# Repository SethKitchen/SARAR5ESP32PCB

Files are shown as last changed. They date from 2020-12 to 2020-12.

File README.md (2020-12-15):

# SARAR5ESP32PCB
An IoT PCB integrating the ESP32 and ublox SARA-R5 . Allows for 5G Cellular, Wi-Fi, and Bluetooth in the same device with low form-factor.

This was an open source contibution sponsored by @hiperionio . Thanks so much! If you like what I'm doing please consider sponsoring as well!

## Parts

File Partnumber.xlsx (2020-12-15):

 |  | Manufacturer | MPN | Comments
10uF | C0402 | Samsung Electro-Mechanics | CL05A106MP8NUB8
1uF | C0402 | Murata Electronics | GRM155R61E105KA12D
100nF | C0402 | AVX Corporation | FS055C104K4Z2A
10nF | C0402 | Murata Electronics | GRM155R71E103KA01D
68pF | C0402 | Yageo | CC0402JRNPO9BN680
15pF | C0402 | KEMET | C0402C150K5GACTU
27pf GRM1555C1... | C0402 | Murata Electronics | GRM1555C1H270JA01J
33pf GRM1555C1... | C0402 | Murata Electronics | GRM1555C1H330JA01D
PESD0402-140 | DIONC1005X43N | Littelfuse Inc. | PESD0402-140
RED | LED-0603 | Broadcom Limited | HSMC-C190
BLUE | LED-0603 | Lite-On Inc. | LTST-C194TBKT
BLUE | LED-0603 | Lite-On Inc. | LTST-C194TBKT
BAT20J | SOD-323 | STMicroelectronics | BAT20JFILM
ANTENNA | TRACE_ANTENNA |  |  | On board PCB antenna
500mA | PTC-1206 | Littelfuse Inc. | 1206L025YR
M20 | 1x20_NOSILK | Amphenol ICC (FCI) | 68000-220HLF
MICROB-PLUG | USB-B-MICRO-SM... | SparkFun | PRT-08533
39nH | L0402 | Murata Electronics | LQG15HN39NJ02D
LQG15HS68NJ02B | LQG15WH0N7B02D | Murata Electronics | LQG15HS68NJ02D
2.7nH | 603 | TDK Electronics Inc. | B82496C3279A000
MBT3904DW1T1 | SC70-6 | ON Semiconductor | MBT3904DW1T3G
RESET | TACTILE_SWITCH | C&K | KMR232GULCLFS
BTN-0 | TACTILE_SWITCH | C&K | KMR232GULCLFS
PAD-JUMPER-3-2O | PAD-JUMPER-3-2O... |  |  | Will not place
JUMPER-PAD-2-N | PAD-JUMPER-2-N... | Yageo | RC0402JR-070RL | Will not place
BC847 | SOT23 | Nexperia | BC847,215
GRM1555C1E680J | INDC1005X45 | Yageo | CC0402JRNPO9BN680
MAX-8 | MAX-8 | U-Blox | MAX-8Q-0-10
AP2112K-3.3V | SOT23-5 | Diodes Incorporated | AP2112K-3.3TRG1
ESP3212 | QFN48-0.4MM | Espressif Systems | ESP32-D0WD
SN74AVC4T774 | TSSOP16 | Texas Instruments | SN74AVC4T774PW
SARA-R5 | Sara-R5 | U-Blox | SARA-R511M
W25Q32FVSS | SOIC-8 | Winbond | W25Q32JVSSIQS
F231XS | SSOP20_L | FTDI, Future Technology Devices International Ltd | FT231XS-R
LTI-SASF54GT | LTI-SASF54GT | Würth Elektronik | 60312002114503
CCM03-3013LFT_... | C&K_CCM03-3013... | C&K | CCM03-3013LFT R102
26MHz | CRYSTAL_SMD-3.2… | ABRACON | ABM3BAIG-26.000MHZ-1Z-T
32.768kHz | CRYSTAL_SMD-3.2... | ABRACON | ABS07W-32.768kHz-K-2-T

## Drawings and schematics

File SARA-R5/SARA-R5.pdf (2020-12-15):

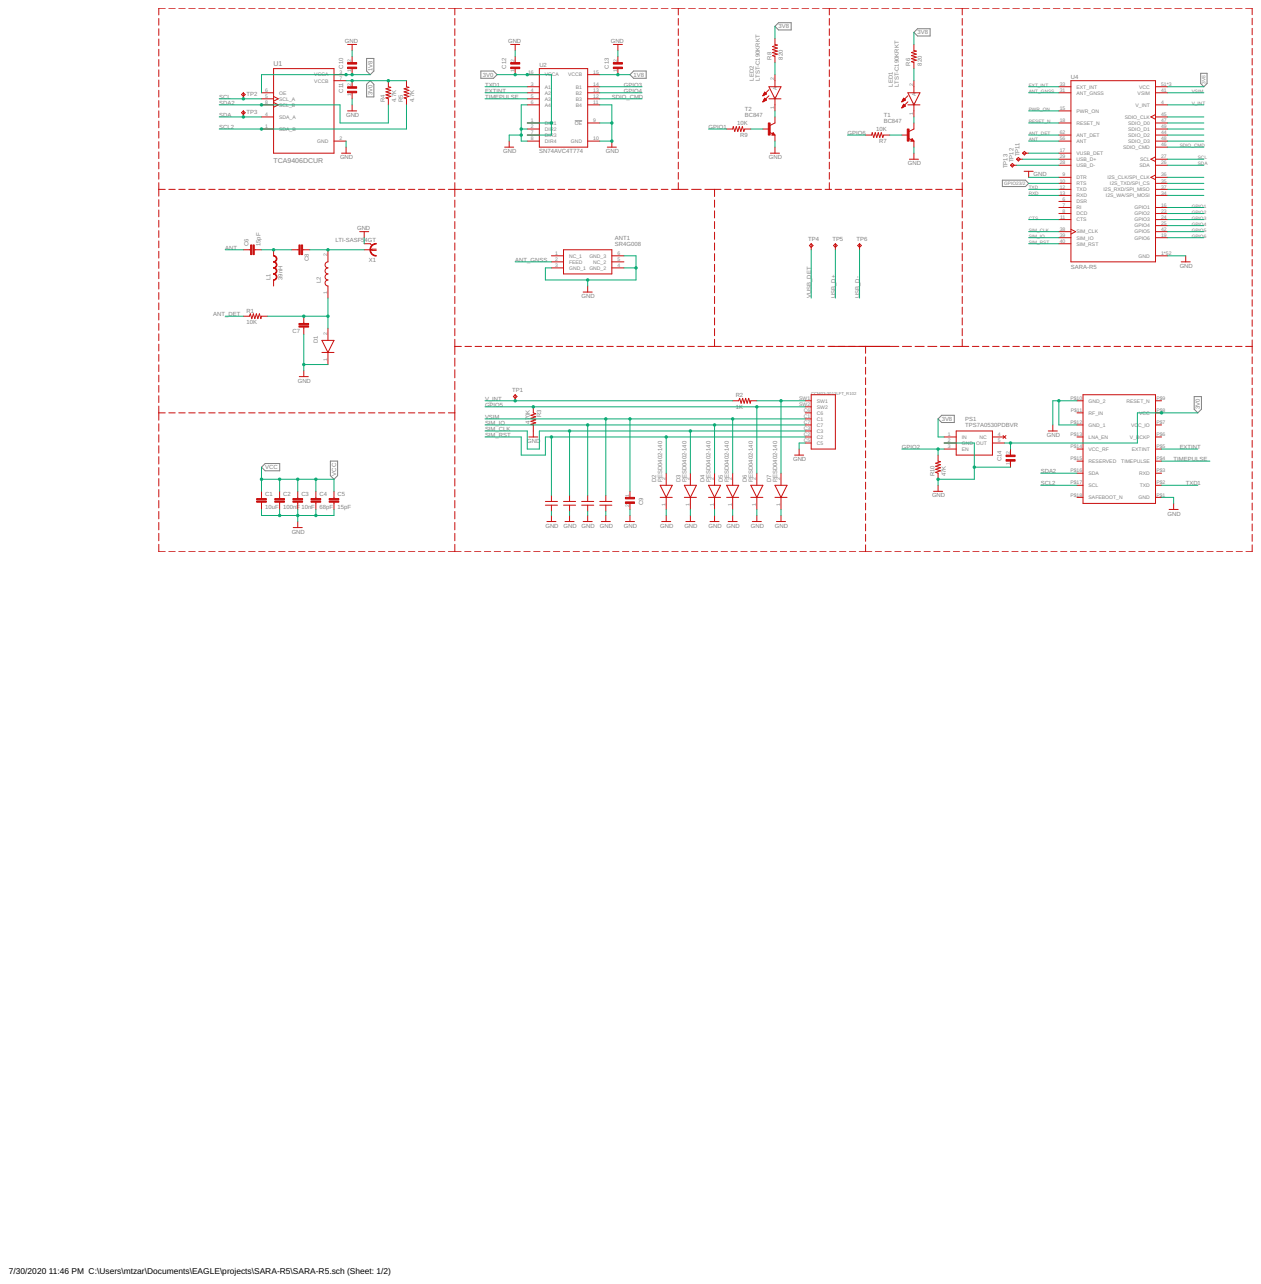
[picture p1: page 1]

7/30/2020 11:46 PM C:\Users\mtzar\Documents\EAGLE\projects\SARA-R5\SARA-R5.sch (Sheet: 1/2)

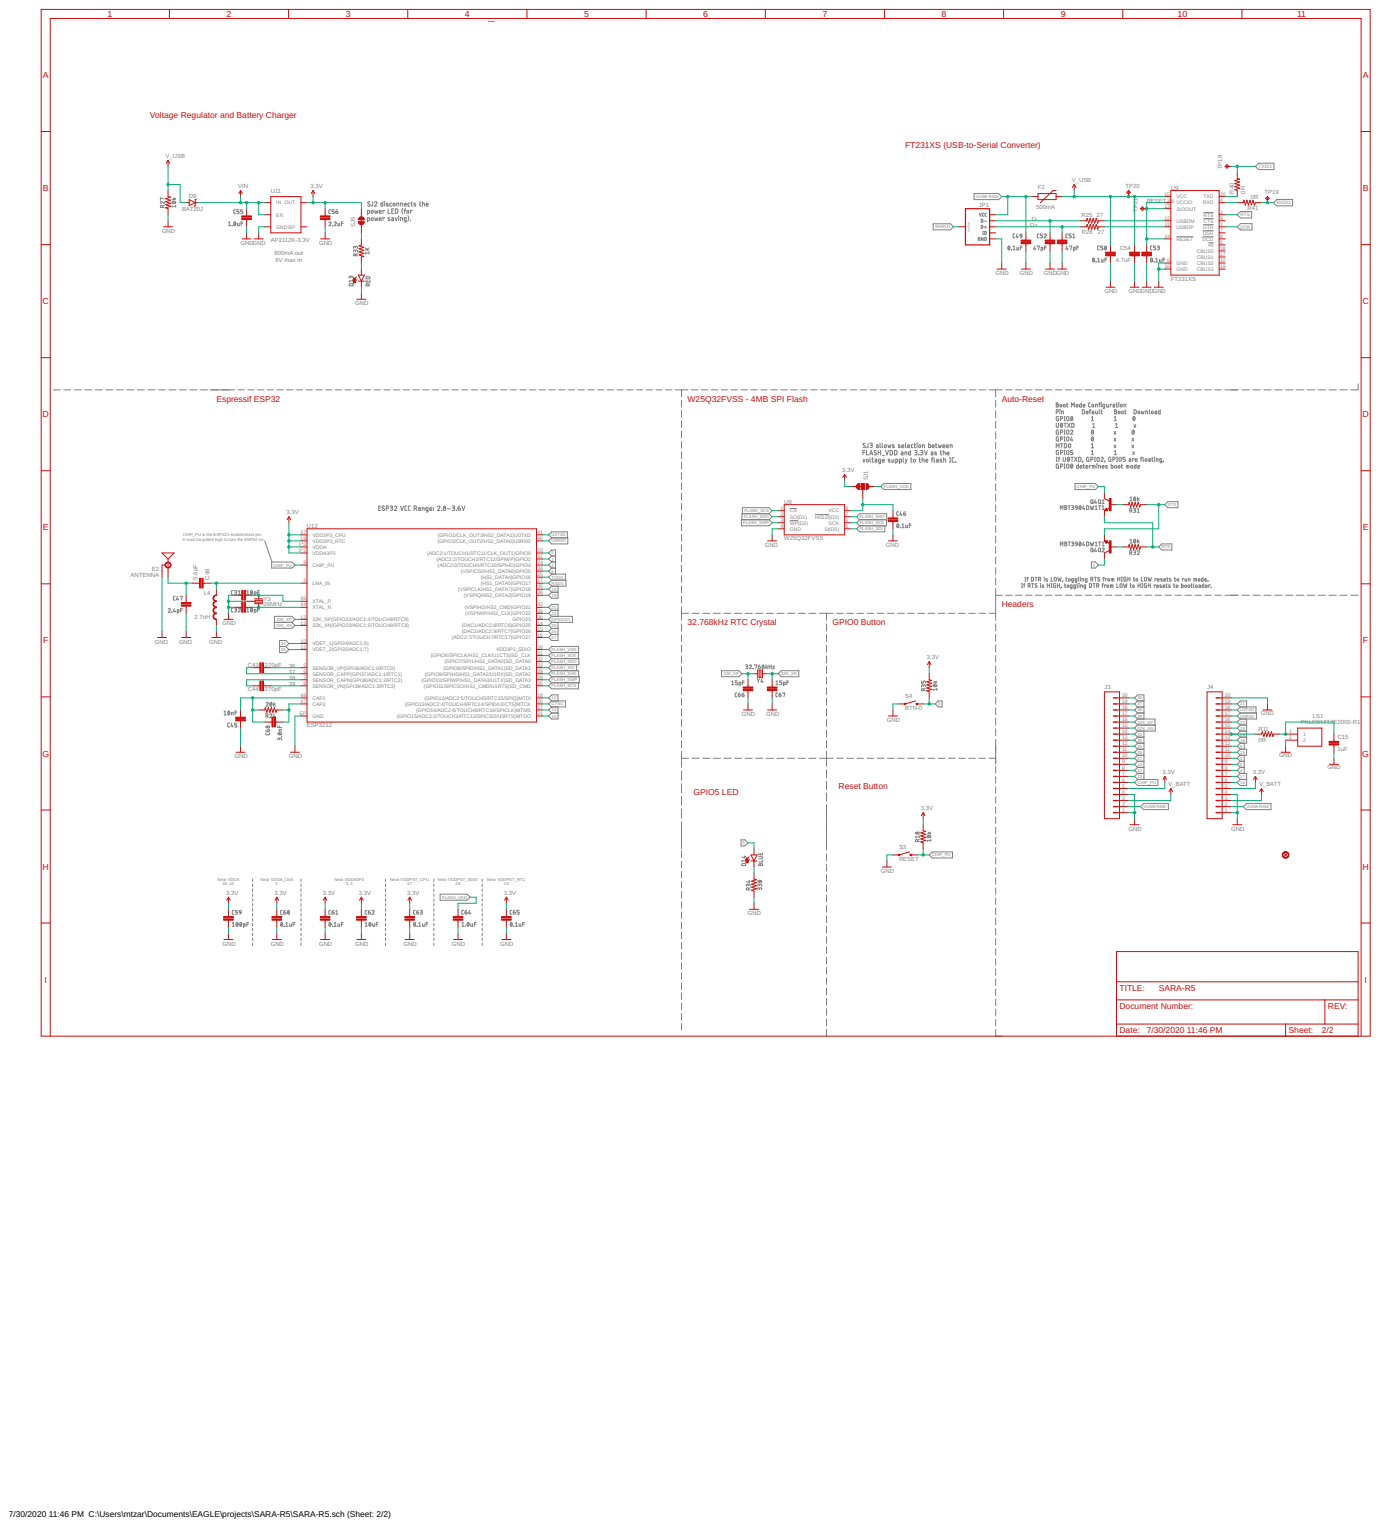
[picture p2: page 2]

Voltage Regulator and Battery Charger

FT231XS (USB-to-Serial Converter)

FLASH_SDO | FLASH_SHD
FLASH_SWP | FLASH_SCK

CHIP_PU is the ESP32's enable/reset pin.

Document Number: | REV:

Date: 7/30/2020 11:46 PM | Sheet: 2/2

7/30/2020 11:46 PM C:\Users\mtzar\Documents\EAGLE\projects\SARA-R5\SARA-R5.sch (Sheet: 2/2)

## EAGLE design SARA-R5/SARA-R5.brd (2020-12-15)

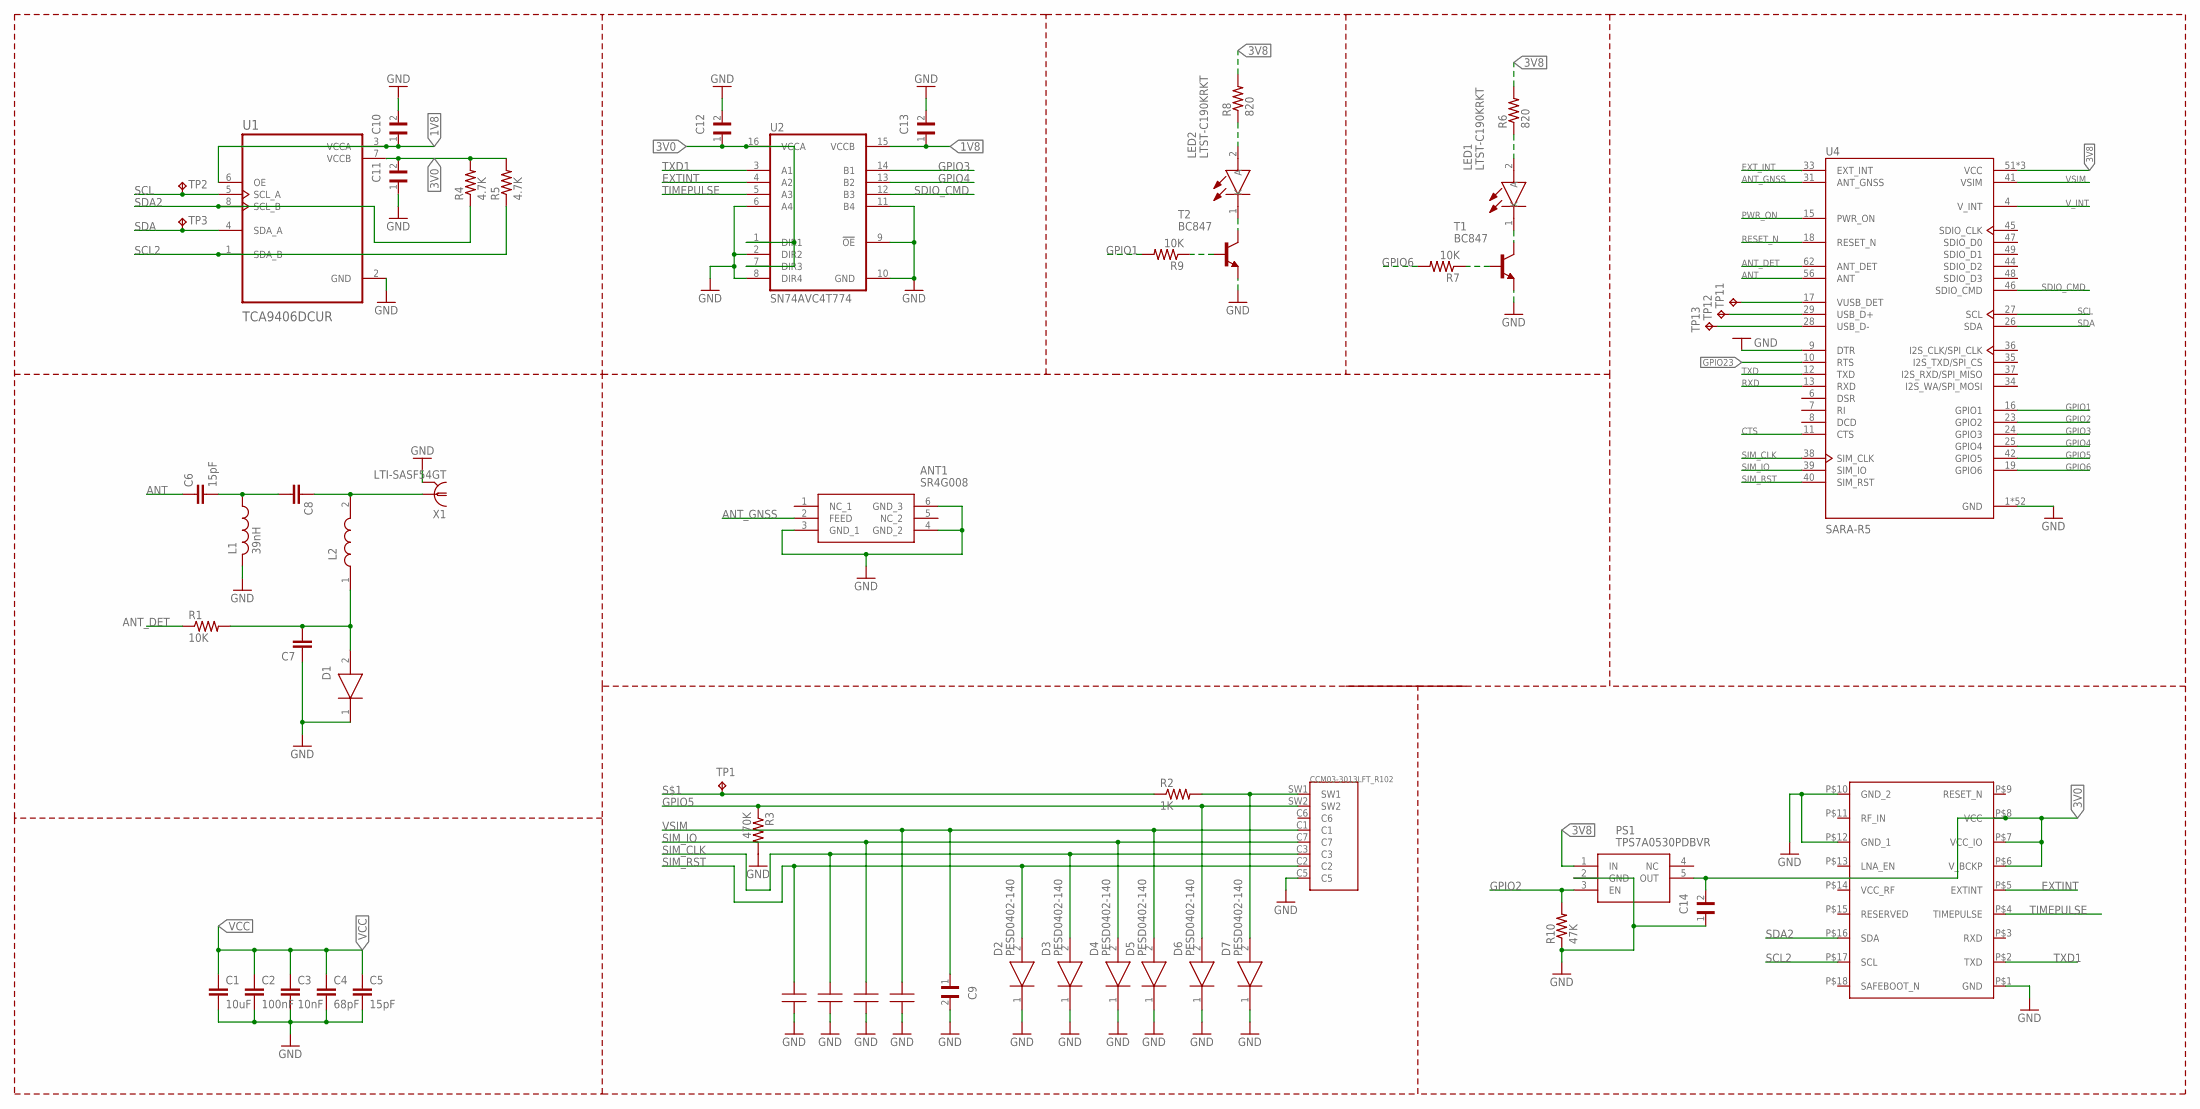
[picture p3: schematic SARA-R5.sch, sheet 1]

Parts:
ANT1: SR4G008
C1: 10uF; C0402
C2: 100nF; C0402
C3: 10nF; C0402
C4: 68pF; C0402
C5, C6: 15pF; C0402
C7: 27pF GRM1555C1H270JA16; C0402
C8: 33pF GRM1555C1H330JA16; C0402
C9, C10, C11, C12, C13, C14: GCM155R71C104KA55J; CAPC1005X55N
D1, D2, D3, D4, D5, D6, D7: PESD0402-140; DIONC1005X43N
L1: 39nH; L0402
L2: LQG15HS68NJ02B; LQG15WH0N7B02D
LED1, LED2: LTST-C190KRKT; LEDC1608X80N
PS1: TPS7A0530PDBVR; SOT95P280X145-5N
R1, R7, R9: 10K; R0402
R2: 1K; R0402
R3: 470K; R0402
R4, R5: 4.7K; R0402
R6, R8: 820; R0402
R10: 47K; R0402
T1, T2: BC847; SOT23
TP1: TPB2,54; B2,54
TP2, TP3, TP11, TP12, TP13: TPB1,27; B1,27
U1: TCA9406DCUR; SOP50P310X90-8N
U2: SN74AVC4T774; TSSOP16
U4: SARA-R5
U$1, U$2, U$3, U$4: GRM1555C1E680JA01; INDC1005X45
U$5: MAX-8
X1: LTI-SASF54GT
X2: CCM03-3013LFT_R102; C&K_CCM03-3013LFTR102

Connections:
1V8: C10.1, C13.1, U1.3 (VCCA), U1.6 (OE), U2.15 (VCCB)
3V0: C11.2, C12.1, C14.2, PS1.5 (OUT), R4.2, R5.2, U1.7 (VCCB), U2.1 (DIR1), U2.7 (DIR3), U2.16 (VCCA), U$5.P$6 (V_BCKP), U$5.P$7 (VCC_IO), U$5.P$8 (VCC)
3V8: PS1.1 (IN), R6.2, R8.2, U4.51 (VCC), U4.52 (VCC), U4.53 (VCC)
ANT: C6.1, U4.56 (ANT)
ANT_DET: R1.1, U4.62 (ANT_DET)
ANT_GNSS: ANT1.2 (FEED), U4.31 (ANT_GNSS)
CTS: U4.11 (CTS); also elsewhere on the board
EXTINT: U2.4 (A2), U$5.P$5 (EXTINT)
EXT_INT: U4.33 (EXT_INT)
GND: ANT1.3 (GND_1), ANT1.4 (GND_2), ANT1.6 (GND_3), C1.2, C2.2, C3.2, C4.2, C5.2, C7.1, C9.2, C10.2, C11.1, C12.2, C13.2, C14.1, D1.1 (K), D2.1 (K), D3.1 (K), D4.1 (K), D5.1 (K), D6.1 (K), D7.1 (K), L1.2, PS1.2 (GND), R3.2, R10.1, T1.2 (E), T2.2 (E), U1.2 (GND), U2.2 (DIR2), U2.6 (A4), U2.8 (DIR4), U2.9 (!OE!), U2.10 (GND), U2.11 (B4), U4.1 (GND), U4.3 (GND), U4.5 (GND), U4.9 (DTR), U4.14 (GND), U4.20 (GND), U4.21 (GND), U4.22 (GND), U4.30 (GND), U4.32 (GND), U4.43 (GND), U4.50 (GND), U4.54 (GND), U4.55 (GND), U4.57 (GND), U4.58 (GND), U4.59 (GND), U4.60 (GND), U4.61 (GND), U4.63 (GND), U4.64 (GND), U4.65 (GND), U4.66 (GND), U4.67 (GND), U4.68 (GND), U4.69 (GND), U4.70 (GND), U4.71 (GND), U4.72 (GND), U4.73 (GND), U4.74 (GND), U4.75 (GND), U4.76 (GND), U4.77 (GND), U4.78 (GND), U4.79 (GND), U4.80 (GND), U4.81 (GND), U4.82 (GND), U4.83 (GND), U4.84 (GND), U4.85 (GND), U4.86 (GND), U4.87 (GND), U4.88 (GND), U4.89 (GND), U4.90 (GND), U4.91 (GND), U4.92 (GND), U4.93 (GND), U4.94 (GND), U4.95 (GND), U4.96 (GND), U$1.2, U$2.2, U$3.2, U$4.2, U$5.P$1 (GND), U$5.P$10 (GND_2), U$5.P$12 (GND_1), X1.2, X1.3 (2), X1.4 (2), X1.5 (2), X2.C5; also elsewhere on the board
GPIO1: R9.2, U4.16 (GPIO1)
GPIO2: PS1.3 (EN), R10.2, U4.23 (GPIO2)
GPIO3: U2.14 (B1), U4.24 (GPIO3)
GPIO4: U2.13 (B2), U4.25 (GPIO4)
GPIO5: D6.2 (A), R3.1, U4.42 (GPIO5), X2.SW2
GPIO6: R7.2, U4.19 (GPIO6)
GPIO23: U4.10 (RTS); also elsewhere on the board
unnamed: C7.2, D1.2 (A), L2.1, R1.2
unnamed: C6.2, C8.2, L1.1
unnamed: D7.2 (A), R2.2, X2.SW1
unnamed: LED1.2 (A), R6.1
unnamed: C8.1, L2.2, X1.1
unnamed: LED1.1 (K), T1.3 (C)
unnamed: R7.1, T1.1 (B)
unnamed: LED2.2 (A), R8.1
unnamed: LED2.1 (K), T2.3 (C)
unnamed: R9.1, T2.1 (B)
unnamed: TP11.TP, U4.17 (VUSB_DET)
unnamed: TP12.TP, U4.29 (USB_D+)
unnamed: TP13.TP, U4.28 (USB_D-)
PWR_ON: U4.15 (PWR_ON); also elsewhere on the board
RESET_N: U4.18 (RESET_N); also elsewhere on the board
RXD: U4.13 (RXD); also elsewhere on the board
S$1: R2.1, TP1.TP
SCL: TP2.TP, U1.5 (SCL_A), U4.27 (SCL)
SCL2: R5.1, U1.1 (SDA_B), U$5.P$17 (SCL)
SDA: TP3.TP, U1.4 (SDA_A), U4.26 (SDA)
SDA2: R4.1, U1.8 (SCL_B), U$5.P$16 (SDA)
SDIO_CMD: U2.12 (B3), U4.46 (SDIO_CMD)
SIM_CLK: D3.2 (A), U4.38 (SIM_CLK), U$2.1, X2.C3
SIM_IO: D4.2 (A), U4.39 (SIM_IO), U$3.1, X2.C7
SIM_RST: D2.2 (A), U4.40 (SIM_RST), U$1.1, X2.C2
TIMEPULSE: U2.5 (A3), U$5.P$4 (TIMEPULSE)
TXD: U4.12 (TXD); also elsewhere on the board
TXD1: U2.3 (A1), U$5.P$2 (TXD)
VCC: C1.1, C2.1, C3.1, C4.1, C5.1
VSIM: C9.1, D5.2 (A), U4.41 (VSIM), U$4.1, X2.C1
V_INT: U4.4 (V_INT)

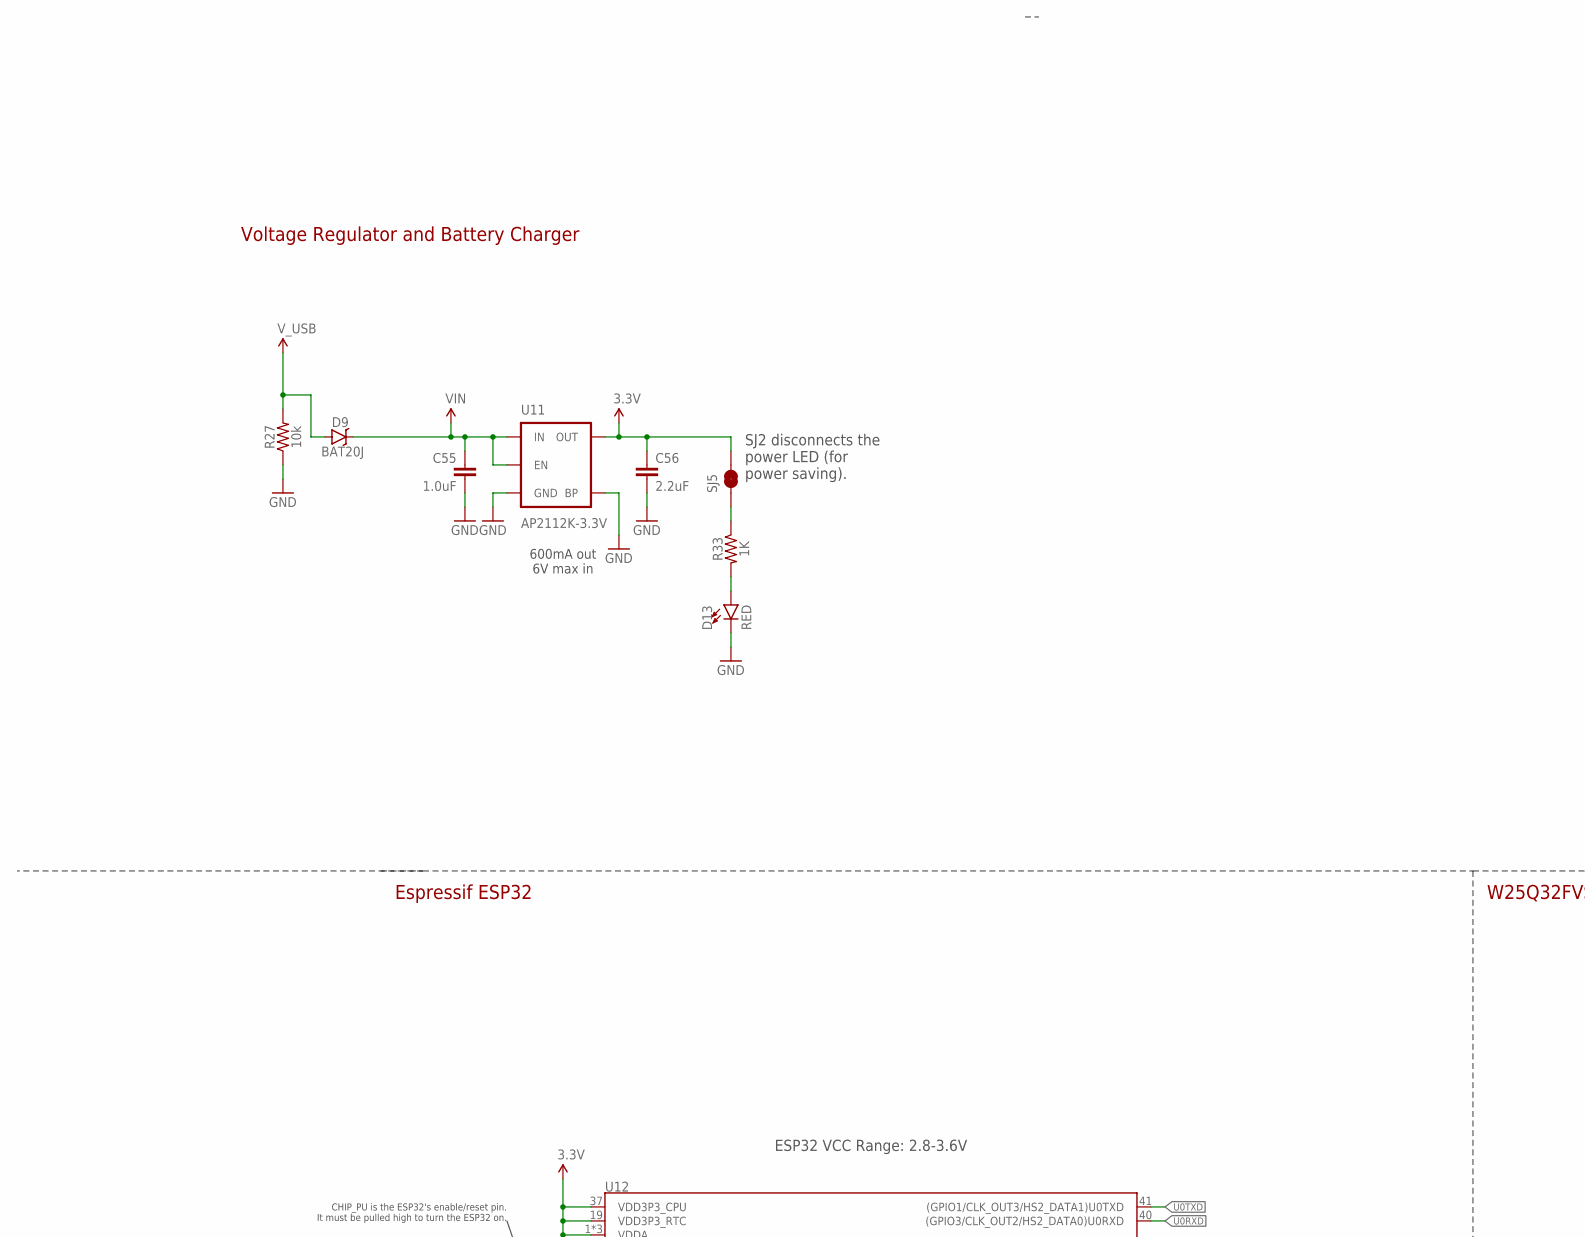
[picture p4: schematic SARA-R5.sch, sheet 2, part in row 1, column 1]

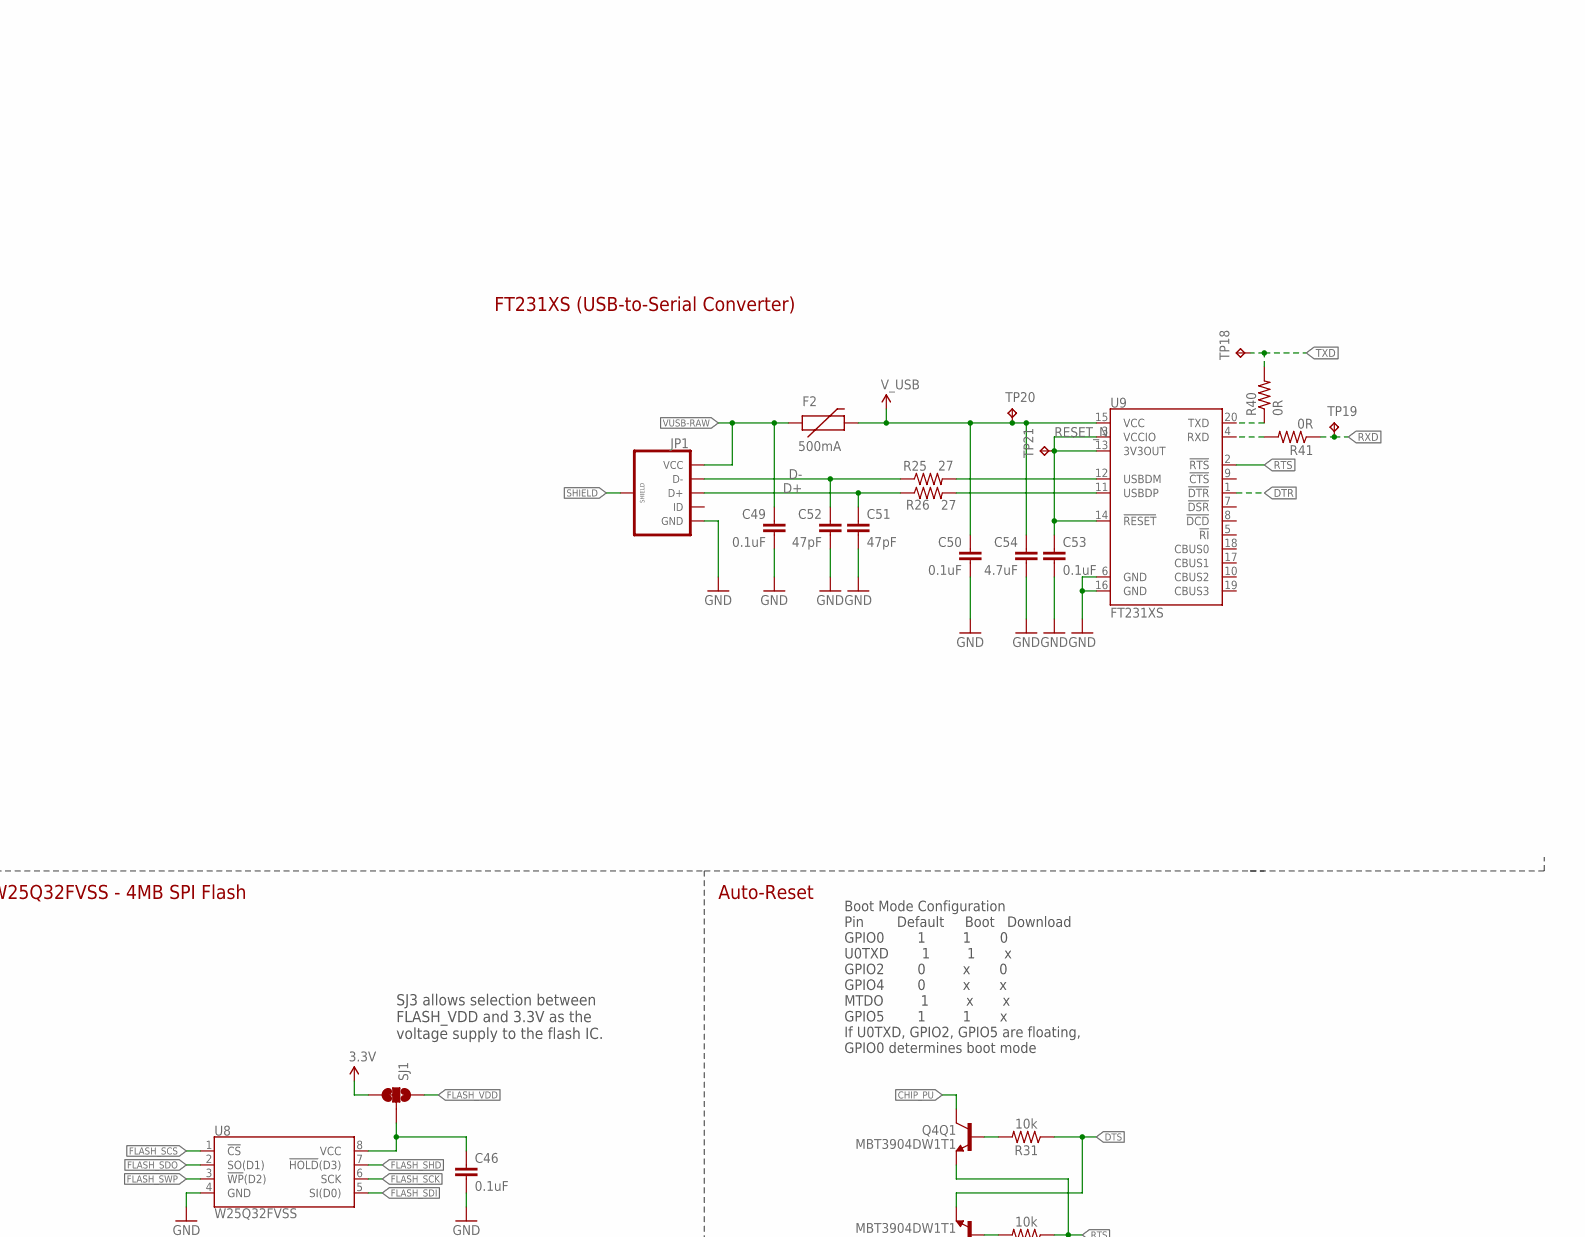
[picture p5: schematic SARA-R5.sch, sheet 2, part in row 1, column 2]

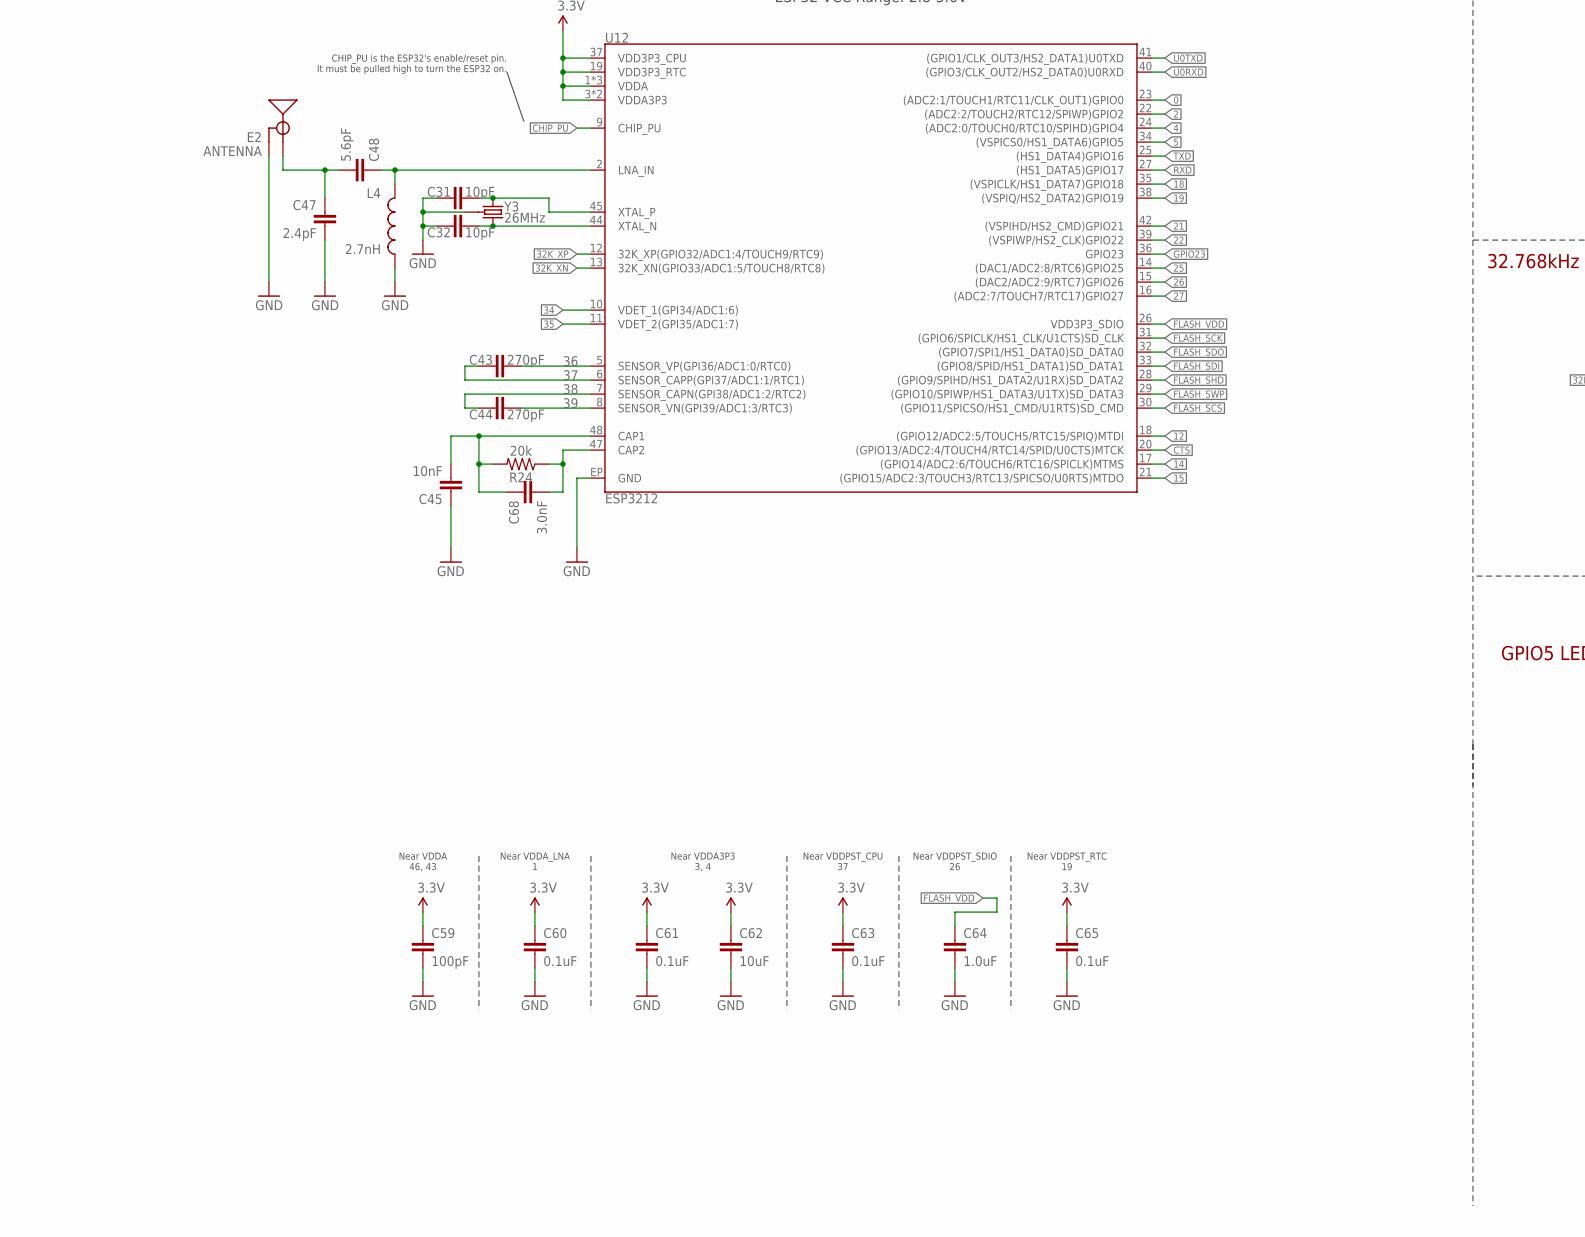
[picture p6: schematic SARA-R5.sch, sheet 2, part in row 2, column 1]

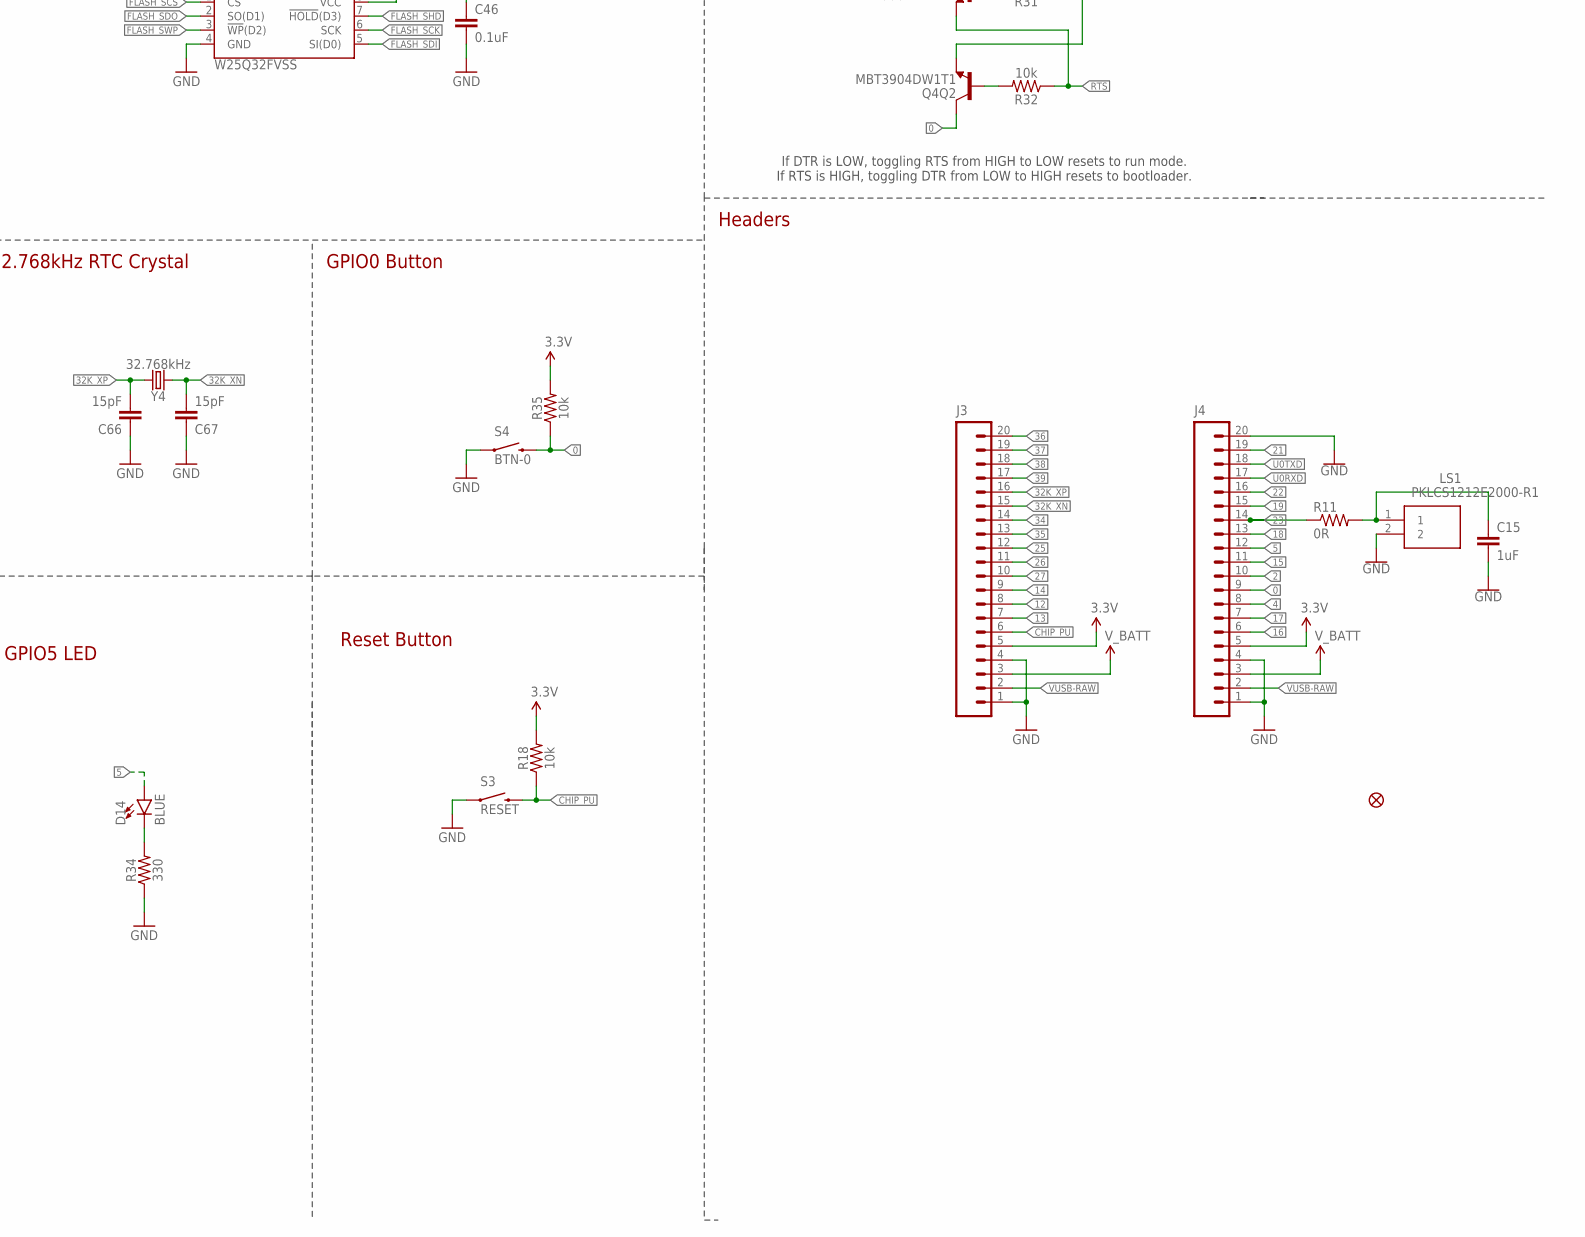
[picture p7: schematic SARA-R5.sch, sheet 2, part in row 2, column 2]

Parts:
C15: 1uF; C0402
C31, C32: 10pF; 0603
C43, C44: 270pF; 0603
C45: 10nF; 0603
C46, C49, C50, C53, C60, C61, C63, C65: 0.1uF; 0603
C47: 2.4pF; 0603
C48: 5.6pF; 0603
C51, C52: 47pF; 0603
C54: 4.7uF; 0603-CAP
C55: 1.0uF; 0805
C56: 2.2uF; 0603
C59: 100pF; 0603
C62: 10uF; 0603
C64: 1.0uF; 0603
C66, C67: 15pF; 0603
C68: 3.0nF; 0603
D9: BAT20J; SOD-323
D13: RED; LED-0603
D14: BLUE; LED-0603
E2: ANTENNA; TRACE_ANTENNA_2.4GHZ_25.7MM_TUNED
F2: 500mA; PTC-1206
FD3: FIDUCIALUFIDUCIAL; MICRO-FIDUCIAL
J3, J4: M20NOSILK; 1X20_NOSILK
JP1: USB_MICROB_PLUGCONN-11752; USB-B-MICRO-SMD_V03
L4: 2.7nH; 0603
LS1: PKLCS1212E2000-R1
Q4: MBT3904DW1T1; SC70-6
R11, R40, R41: 0R; R0402
R18, R27, R31, R32, R35: 10k; 0603
R24: 20k; 0603
R25, R26: 27; 0603
R33: 1K; 0603
R34: 330; 0603
S3: RESET; TACTILE_SWITCH_SMD_4.6X2.8MM
S4: BTN-0; TACTILE_SWITCH_SMD_4.6X2.8MM
SJ1: JUMPER-PAD-3-2OF3_NC_BY_TRACE_SMALL; PAD-JUMPER-3-2OF3_NC_BY_TRACE_YES_SILK_FULL_BOX
SJ5: JUMPER-PAD-2-NC_BY_TRACE; PAD-JUMPER-2-NC_BY_TRACE_YES_SILK
TP18, TP19, TP20, TP21: TPB1,27; B1,27
U8: W25Q32FVSS; SOIC-8
U9: FT231XS; SSOP20_L
U11: AP2112K-3.3V; SOT23-5
U12: ESP3212; QFN48-0.4MM
Y3: 26MHz; CRYSTAL-SMD-3.2X2.5
Y4: 32.768kHz; CRYSTAL-SMD-3.2X1.5MM

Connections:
0: J4.9, Q4.6 (C), R35.1, S4.3 (2), S4.4 (2), U12.23 ((ADC2:1/TOUCH1/RTC11/CLK_OUT1)GPIO0)
2: J4.10, U12.22 ((ADC2:2/TOUCH2/RTC12/SPIWP)GPIO2)
3.3V: C56.1, C59.1, C60.1, C61.1, C62.1, C63.1, C65.1, J3.5, J4.5, R18.2, R35.2, SJ1.3, SJ5.2, U11.5 (OUT), U12.1 (VDDA), U12.3 (VDDA3P3), U12.4 (VDDA3P3), U12.19 (VDD3P3_RTC), U12.37 (VDD3P3_CPU), U12.43 (VDDA), U12.46 (VDDA)
4: J4.8, U12.24 ((ADC2:0/TOUCH0/RTC10/SPIHD)GPIO4)
5: D14.A, J4.12, U12.34 ((VSPICS0/HS1_DATA6)GPIO5)
12: J3.8, U12.18 ((GPIO12/ADC2:5/TOUCH5/RTC15/SPIQ)MTDI)
13: J3.7
14: J3.9, U12.17 ((GPIO14/ADC2:6/TOUCH6/RTC16/SPICLK)MTMS)
15: J4.11, U12.21 ((GPIO15/ADC2:3/TOUCH3/RTC13/SPICSO/U0RT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)
16: J4.6
17: J4.7
18: J4.13, U12.35 ((VSPICLK/HS1_DATA7)GPIO18)
19: J4.15, U12.38 ((VSPIQ/HS2_DATA2)GPIO19)
21: J4.19, U12.42 ((VSPIHD/HS2_CMD)GPIO21)
22: J4.16, U12.39 ((VSPIWP/HS2_CLK)GPIO22)
23: C15.1, J4.14, LS1.1, R11.1, R11.2
25: J3.12, U12.14 ((DAC1/ADC2:8/RTC6)GPIO25)
26: J3.11, U12.15 ((DAC2/ADC2:9/RTC7)GPIO26)
27: J3.10, U12.16 ((ADC2:7/TOUCH7/RTC17)GPIO27)
32K_XN: C67.2, J3.15, U12.13 (32K_XN(GPIO33/ADC1:5/TOUCH8/RTC8)), Y4.P$2 (2)
32K_XP: C66.2, J3.16, U12.12 (32K_XP(GPIO32/ADC1:4/TOUCH9/RTC9)), Y4.P$1 (1)
34: J3.14, U12.10 (VDET_1(GPI34/ADC1:6))
35: J3.13, U12.11 (VDET_2(GPI35/ADC1:7))
36: C43.2, J3.20, U12.5 (SENSOR_VP(GPI36/ADC1:0/RTC0))
37: C43.1, J3.19, U12.6 (SENSOR_CAPP(GPI37/ADC1:1/RTC1))
38: C44.1, J3.18, U12.7 (SENSOR_CAPN(GPI38/ADC1:2/RTC2))
39: C44.2, J3.17, U12.8 (SENSOR_VN(GPI39/ADC1:3/RTC3))
CAP_10N1: C45.2, C68.1, R24.2, U12.48 (CAP1)
CHIP_PU: J3.6, Q4.3 (C), R18.1, S3.3 (2), S3.4 (2), U12.9 (CHIP_PU)
CTS: U12.20 ((GPIO13/ADC2:4/TOUCH4/RTC14/SPID/U0CTS)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); also elsewhere on the board
D+: C51.1, JP1.D+, R26.1
D-: C52.1, JP1.D-, R25.1
DTR: U9.1 (!DTR)
DTS: Q4.1 (E), R31.1
FLASH_SCK: U8.6 (SCK), U12.31 ((GPIO6/SPICLK/HS1_CLK/U1CTS)SD_CLK)
FLASH_SCS: U8.1 (!CS!), U12.30 ((GPIO11/SPICSO/HS1_CMD/U1RTS)SD_CMD)
FLASH_SDI: U8.5 (SI(D0)), U12.33 ((GPIO8/SPID/HS1_DATA1)SD_DATA1)
FLASH_SDO: U8.2 (SO(D1)), U12.32 ((GPIO7/SPI1/HS1_DATA0)SD_DATA0)
FLASH_SHD: U8.7 (!HOLD!(D3)), U12.28 ((GPIO9/SPIHD/HS1_DATA2/U1RX)SD_DATA2)
FLASH_SWP: U8.3 (!WP!(D2)), U12.29 ((GPIO10/SPIWP/HS1_DATA3/U1TX)SD_DATA3)
FLASH_VDD: C64.1, SJ1.1, U12.26 (VDD3P3_SDIO)
GND: C15.2, C31.1, C32.1, C45.1, C46.2, C47.2, C49.2, C50.2, C51.2, C52.2, C53.2, C54.2, C55.2, C56.2, C59.2, C60.2, C61.2, C62.2, C63.2, C64.2, C65.2, C66.1, C67.1, D13.C, E2.GND, E2.GND2 (GND), J3.1, J3.4, J4.1, J4.4, J4.20, JP1.GND, L4.2, LS1.2, R27.1, R34.1, S3.1, S3.2 (1), S4.1, S4.2 (1), U8.4 (GND), U9.6 (GND), U9.16 (GND), U11.2 (GND), U11.4 (BP), U12.EP (GND), Y3.2 (GND), Y3.4 (GND); also elsewhere on the board
GPIO23: U12.36 (GPIO23); also elsewhere on the board
LNA_IN1: C48.1, L4.1, U12.2 (LNA_IN)
unnamed: C46.1, SJ1.2, U8.8 (VCC)
unnamed: R25.2, U9.12 (USBDM)
unnamed: R26.2, U9.11 (USBDP)
unnamed: Q4.5 (B), R31.2
unnamed: Q4.2 (B), R32.2
unnamed: C31.2, U12.45 (XTAL_P), Y3.1
unnamed: C32.2, U12.44 (XTAL_N), Y3.3 (2)
unnamed: D13.A, R33.2
unnamed: R33.1, SJ5.1
unnamed: D14.C, R34.2
unnamed: C68.2, R24.1, U12.47 (CAP2)
unnamed: R40.1, U9.20 (TXD)
unnamed: R41.2, U9.4 (RXD)
PWR_ON: C50.1, C54.1, F2.2, TP20.TP, U9.15 (VCC); also elsewhere on the board
RESET_N: C53.1, TP21.TP, U9.3 (VCCIO), U9.13 (3V3OUT), U9.14 (!RESET); also elsewhere on the board
RTS: Q4.4 (E), R32.1, U9.2 (!RTS)
RXD: R41.1, TP19.TP, U12.27 ((HS1_DATA5)GPIO17); also elsewhere on the board
SHIELD: JP1.SHIELD1 (SHIELD), JP1.SHIELD2 (SHIELD), JP1.SHIELD3 (SHIELD)
TRACE_ANT1: C47.1, C48.2, E2.ANT (SIGNAL)
TXD: R40.2, TP18.TP, U12.25 ((HS1_DATA4)GPIO16); also elsewhere on the board
U0RXD: J4.17, U12.40 ((GPIO3/CLK_OUT2/HS2_DATA0)U0RXD)
U0TXD: J4.18, U12.41 ((GPIO1/CLK_OUT3/HS2_DATA1)U0TXD)
VIN: C55.1, D9.C, U11.1 (IN), U11.3 (EN)
VUSB-RAW: C49.1, F2.1, J3.2, J4.2, JP1.VBUS (VCC)
V_BATT: J3.3, J4.3
V_USB: D9.A, R27.2

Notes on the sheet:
Boot Mode Configuration Pin Default Boot Download GPIO0 1 1 0 U0TXD 1 1 x GPIO2 0 x 0 GPIO4 0 x x MTDO 1 x x GPIO5 1 1 x If U0TXD, GPIO2, GPIO5 are floating, GPIO0 determines boot mode
FT231XS (USB-to-Serial Converter)
Voltage Regulator and Battery Charger
600mA out 6V max in
Auto-Reset
Near VDDA 46, 43
Near VDDA_LNA 1
Near VDDA3P3 3, 4
Near VDDPST_CPU 37
Near VDDPST_SDIO 26
Near VDDPST_RTC 19
Espressif ESP32
W25Q32FVSS - 4MB SPI Flash
32.768kHz RTC Crystal
GPIO0 Button
Reset Button
GPIO5 LED
Headers
ESP32 VCC Range: 2.8-3.6V
SJ3 allows selection between FLASH_VDD and 3.3V as the voltage supply to the flash IC.
SJ2 disconnects the power LED (for power saving).
If DTR is LOW, toggling RTS from HIGH to LOW resets to run mode. If RTS is HIGH, toggling DTR from LOW to HIGH resets to bootloader.
CHIP_PU is the ESP32's enable/reset pin. It must be pulled high to turn the ESP32 on.

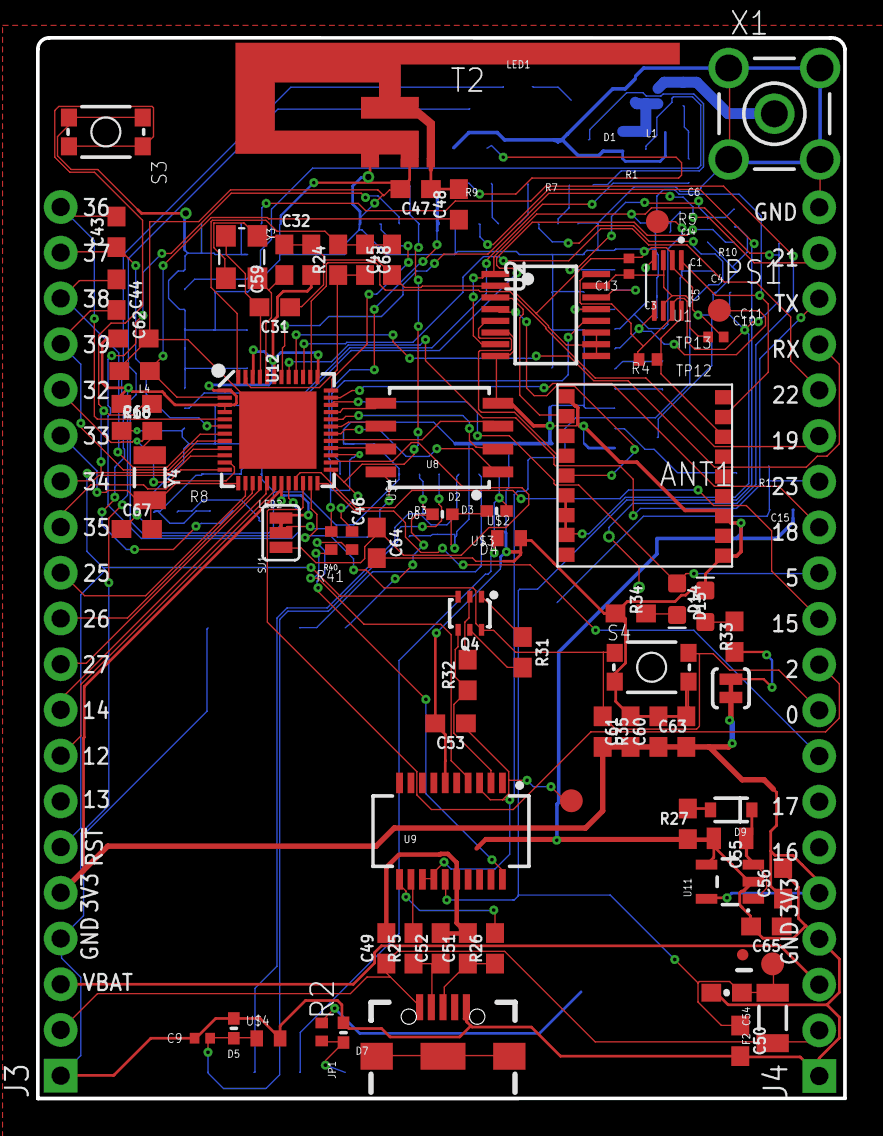
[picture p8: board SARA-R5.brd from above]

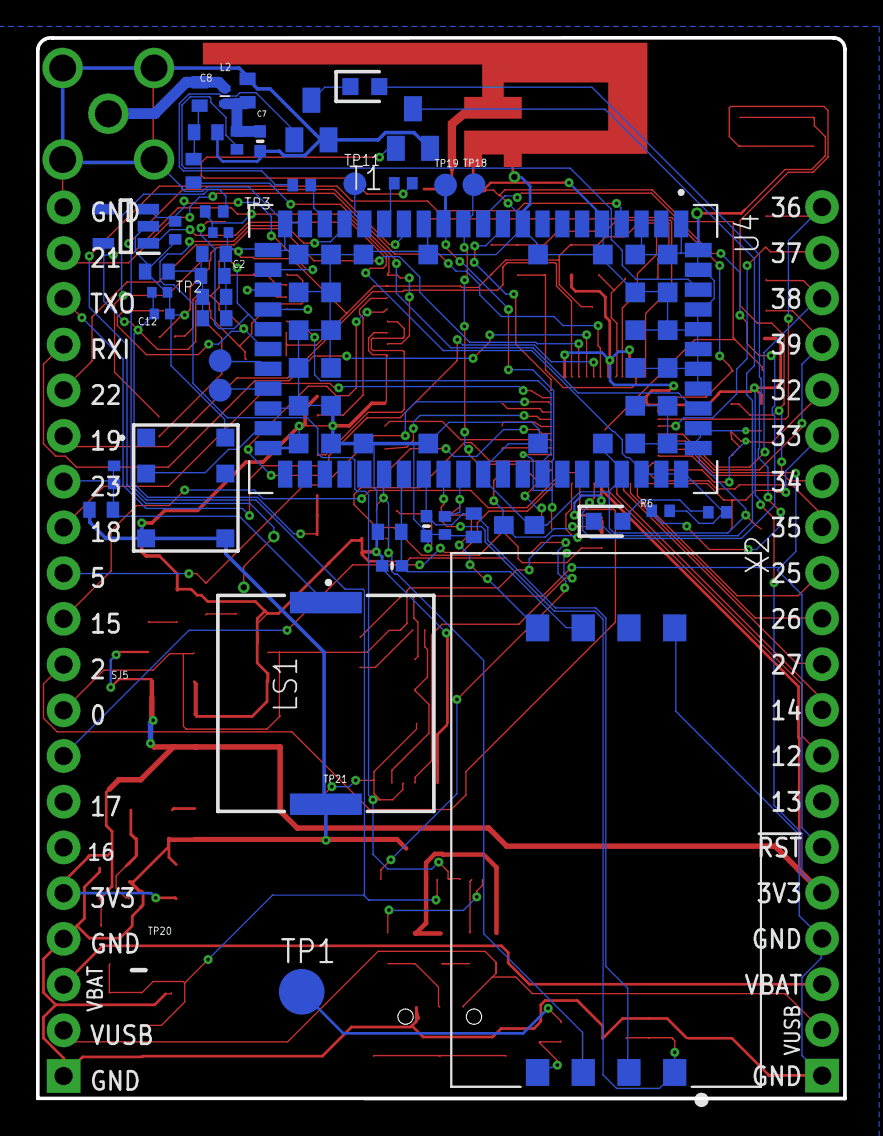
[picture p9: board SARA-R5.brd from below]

Board: 2 copper layers, 44.8 x 58.9 mm, 121 parts (44 on the bottom side), 105 nets.

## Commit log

2020-12-15 initial board commit
    [SARA-R5.brd, SARA-R5.sch]
2020-12-15 add part numbers
    [Partnumber.xlsx]

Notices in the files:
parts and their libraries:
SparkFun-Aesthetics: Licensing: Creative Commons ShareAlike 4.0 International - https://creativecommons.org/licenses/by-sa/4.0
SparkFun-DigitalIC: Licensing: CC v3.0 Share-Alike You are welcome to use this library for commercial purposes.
